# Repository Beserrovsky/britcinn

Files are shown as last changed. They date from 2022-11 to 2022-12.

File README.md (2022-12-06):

# Britney Cinnamon
Britney Cinnamon, an IOT device embedded in the light switch.

[versão em portguês aqui](README-pt.md)

## Idea

Check out [idea PDF](idea.pdf)

## Features

- Control over light switchs
- Door locking capability
- Voice commands
- Mqtt-based communication
- Data analysis via Database storage and API

## Stack

- Micropython for client firmware
- HiveMQ as public broker
- NodeJS + MongoDB app for storage and API access

## Relevant Links

 - Presentation video: https://youtu.be/LhZvgNEXjJY
 - Implementation and demonstration video: https://youtu.be/GOQ3h5-p_FI
 - Driver folder: https://drive.google.com/drive/u/0/folders/1Ou_RRr1SyYoGhryZdT9D95lgfnK7g_yX 
 - Secondary Repository (web page and app): https://github.com/Beserrovsky/britcinn-website

## Credits

[Hanashiro](https://github.com/Hanashiro2001)

[Felipe Beserra](https://github.com/Beserrovsky)

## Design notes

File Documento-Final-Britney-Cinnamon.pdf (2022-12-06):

### Escola Politécnica da Universidade de São Paulo

PSI 3542 - Sistemas Embarcados para IoT

Felipe Beserra (13683702)
Gabriel Kiyoki Hanashiro (13682020)

# Projeto Final: Britney Cinnamon

### São Paulo

2022

Felipe Beserra, Gabriel K. Hanashiro

# Projeto Final: Britney Cinnamon

Orientadores:
Prof. Sergio Takeo Kofuji
Fabrício Mansilla

São Paulo
2022

Resumo

Internet das Coisas (ou IoT) é a conexão dos objetos mundanos a internet, podendo ser aplicado em diversas áreas (médica, industrial, automação, etc). Aqui, descreve-se um projeto desenvolvido por alunos de graduação na Escola Politécnica da Universidade de São Paulo, apresentando um sistema completo de IoT cujas funcionalidades envolvem travas e lâmpadas inteligentes.

Sumário

Resumo | 2
1. Requisitos do projeto final | 4
1.1 Entregas | 4
1.2 Requisitos | 4
2. Projeto Final | 4
2.1 Lista de Componentes | 4
2.2 Descrição do sistema | 5
2.3 Implementação do sistema | 7
2.3.1 ESP client | 7
2.3.2 RASP client | 7
2.4 Utilização dos dispositivos | 8
2.4.1 Modelos | 8
2.4.2 Aplicativo e página web | 10
3. Marketing | 13
3.1 Comparação de mercado | 13
3.2 Marca | 14
4. Links importantes | 14
4.1 Links relacionados ao grupo | 14
4.2 Links de produtos para comparação de preços | 15

1. Requisitos do projeto final

O trabalho final da disciplina de IoT para Sistemas Embarcados é projetar e aplicar uma solução completa de IoT usando dispositivos embarcados de IoT.

1.1 Entregas
O trabalho final têm como entregas:
- Minimum Viable Product (MVP);
- Folder do sistema;
- Apresentação do projeto (marketing e técnica);
- Vídeo tutorial no youtube do projeto, com detalhes do passo-a-passo da implementação do sistema. Deve conter uma demonstração de uso;
- Arquivos dos códigos publicados no GitHub;
- Tutoriais no GitHub.

1.2 Requisitos
O produto final deverá englobar:
- Um (ou mais) dispositivo embarcado de IoT para sensoriamento/atuação, com capacidade de comunicação MQTT;
- Um Smart IoT device/gateway/edge com capacidade de interação humano-máquina por voz para gerenciamento dos dispositivos de IoT embarcados e integração com serviços em nuvem;
- Uma aplicação de monitoramento em nuvem, capaz de conversar com usuários através de redes sociais e página web;
- Um aplicativo para smartphone android.
2. Projeto Final

2.1 Lista de Componentes
Os componentes usados no projeto foram:
- Raspberry Pi;
- ESP32;
- DHT11;
- Servo motor;
- Módulo relé 3.3V - 127V;
- LED (para o protótipo);
- Resistor (para o protótipo);
- Mini interruptor de alternância (para o protótipo);
- Borne 2 vias;
- Mini fonte 5V.

2.2 Descrição do sistema
O projeto final do grupo usa um ESP32 como dispositivo IoT que se comunica com o smart hub unicamente via MQTT. O dispositivo IoT controlado seria instalado dentro do interruptor do cômodo e controlaria a luz com um relé, de maneira integrada com o próprio interruptor (ou seja, a mudança de estado é o que altera a luz), um DHT11 para captar a temperatura e umidade, e um servo motor atuando como o mecanismo de uma trava.
A alimentação do dispositivo será realizada com os próprios cabos de alimentação da lâmpada na parede, apenas passando por um conversor de tensão para se adaptar ao ESP32 (para o caso do protótipo, teremos um carregador de celular para fazer essa conversão).
Por ser um protótipo e devido às diversas mudanças de design pelo qual o projeto passa, o grupo usou uma placa ilhada de fibra de vidro 10x5 centímetros para fazer o sistema de alimentação do ESP (mantendo espaço para os outros componentes, para ter uma ideia de tamanho) e usou uma protoboard e um LED para realizar os testes e comprovar o funcionamento, imagens 1 e 2 respectivamente. Além disso, por não termos um microfone compatível com o Raspberry Pi, rodamos o código do smart hub no computador, porém ele é compatível com o mini-computador (apenas alterando o contexto do rhino para ser compatível com o sistema).

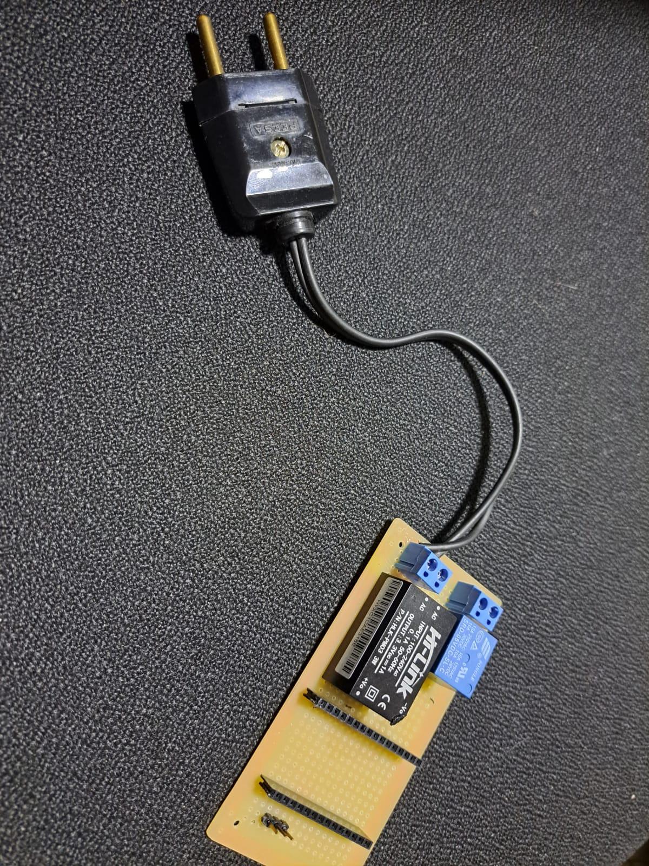
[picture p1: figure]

Imagem 1 - Protótipo do dispositivo IoT na protoboard. FONTE: Autoral.

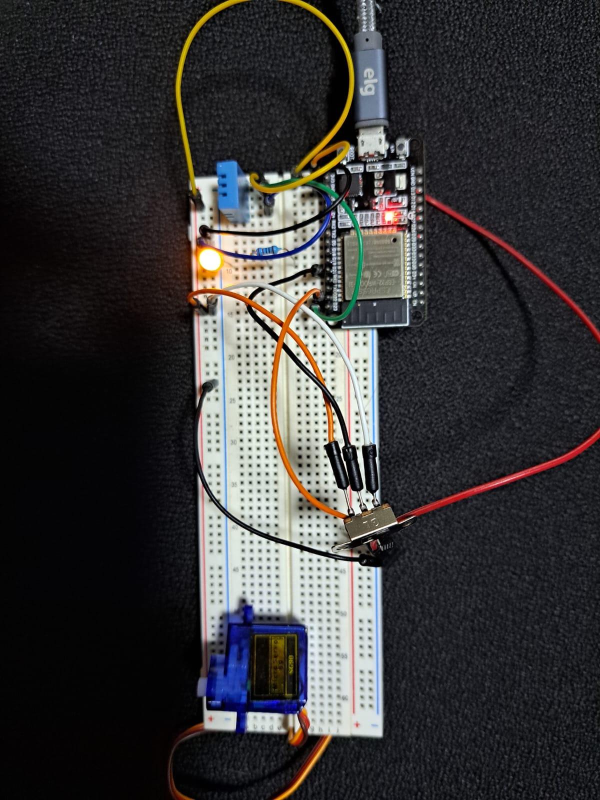
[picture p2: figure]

Imagem 1 - Protótipo do dispositivo IoT na protoboard. FONTE: Autoral.

A comunicação MQTT é realizada utilizando o broker EMQX, um serviço open source. A estrutura de comunicação, incluindo o broker, pode ser vista na imagem 2.

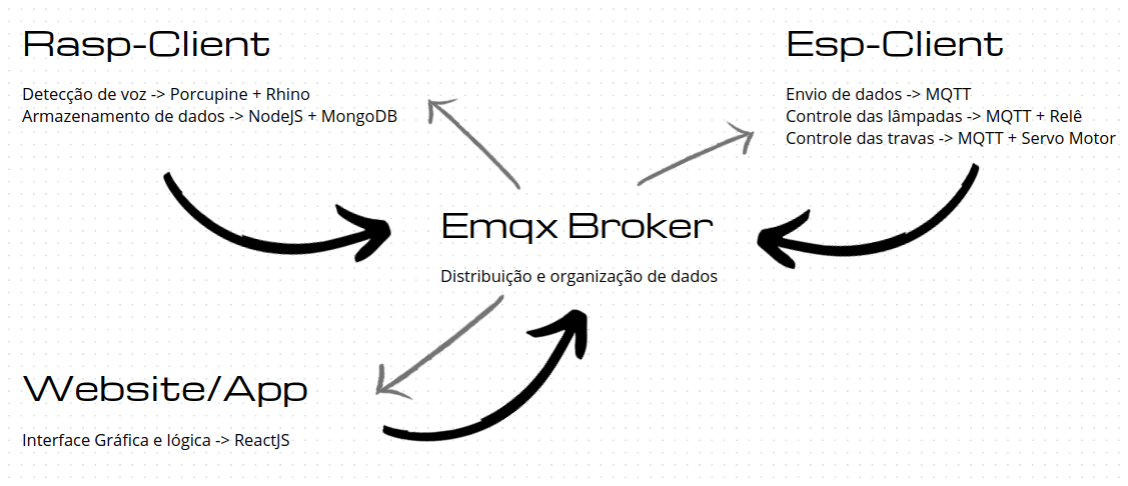
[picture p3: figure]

Imagem 2 - Estrutura de comunicação dos dispositivos. FONTE: Autoral.

O smart hub, no caso o raspberry pi, conecta na internet e se comunica com o ESP32 via MQTT, como mencionado anteriormente. Ele é a interface para comunicação humano-máquina, ou seja, interação por voz para controle do dispositivo IoT, funcionando com o PicoVoice (usando Porcupine e Rhino).
Temos apenas a palavra “Cinnamon” como wake word do dispositivo, pois “Britney” não está incluído no dicionário do PicoVoice. Apesar do porcupine funcionar com uma palavra em inglês, o speech-to-intent do Rhino funciona de acordo com a língua portuguesa; treinamos o contexto dele para obedecer aos comandos de ligar, desligar, trancar e destrancar.

2.3 Implementação do sistema

2.3.1 ESP client
O ESP32, como mencionado anteriormente, envia dados de temperatura e umidade do DHT11, o estado da lâmpada e da trava a cada 5 segundos, aproximadamente, além de um aviso toda vez que liga; e recebe comandos de mudança de estado da lâmpada e da trava. Ambos trocando informações com o Raspberry Pi via MQTT (todos os dados são enviados no formato JSON, sigla para JavaScript Object Notation).
Para isso, existem os códigos boot.py (para conexão com internet) e o código main.py, que utilizam as bibliotecas components.py (escrita pelo grupo especificamente para este projeto) e mqttsimple.py (de uso público). No main.py, há, inicialmente, uma rotina para tentar uma conexão com o broker MQTT, que caso falhe, o dispositivo reinicia e tenta de novo. Em seguida, são definidas funções para verificar se há novas informações em algum tópico MQTT e para mandar os dados do DHT11 que serão armazenados no Raspberry Pi para possíveis análises dos dados. Além delas, uma última função chama a rotina dos componentes para realizar a coleta de dados do DHT e o funcionamento dos outros componentes de acordo com as mudanças, ou falta delas.
No caso do interruptor inteligente, diferentemente de um comum, não há um estado ligado e um estado desligado, mas sim, um funcionamento semelhante a de um push button, pois a mudança de estado (apertando a switch, independente de direção) acende ou apaga a luz.

2.3.2 RASP client
O Raspberry Pi é o smart hub, isto é, o centro de inteligência que atua como assistente controlado por voz, host do servidor do app e dos outros serviços necessários para o funcionamento do dispositivo. Para tal, ele possui uma rotina para iniciar a comunicação MQTT, e uma conexão direta com o MongoDB (software de banco de dados).
Além disso, tem-se uma implementação do sistema porcupine, que serve para identificar a wake word (treinado com a palavra “Cinnamon”) e rhino, um software de speech-to-intent (com o contexto elaborado pelo grupo) para identificação de voz, ambos serviços gratuitos, porém limitados, do PicoVoice.
Por fim, o Raspberry Pi também possui a rotina necessária para rodar a página da web e o aplicativo.

2.4 Utilização dos dispositivos

2.4.1 Modelos
Para utilizar o sistema, primeiramente, elaboramos uma casa fictícia usando o aplicativo Revit da Autodesk para modelar o Floorplan da imagem 3, ele possui 2 quartos, 1 cozinha, 2 banheiros, 1 garagem, 1 sala e 1 área de serviço.

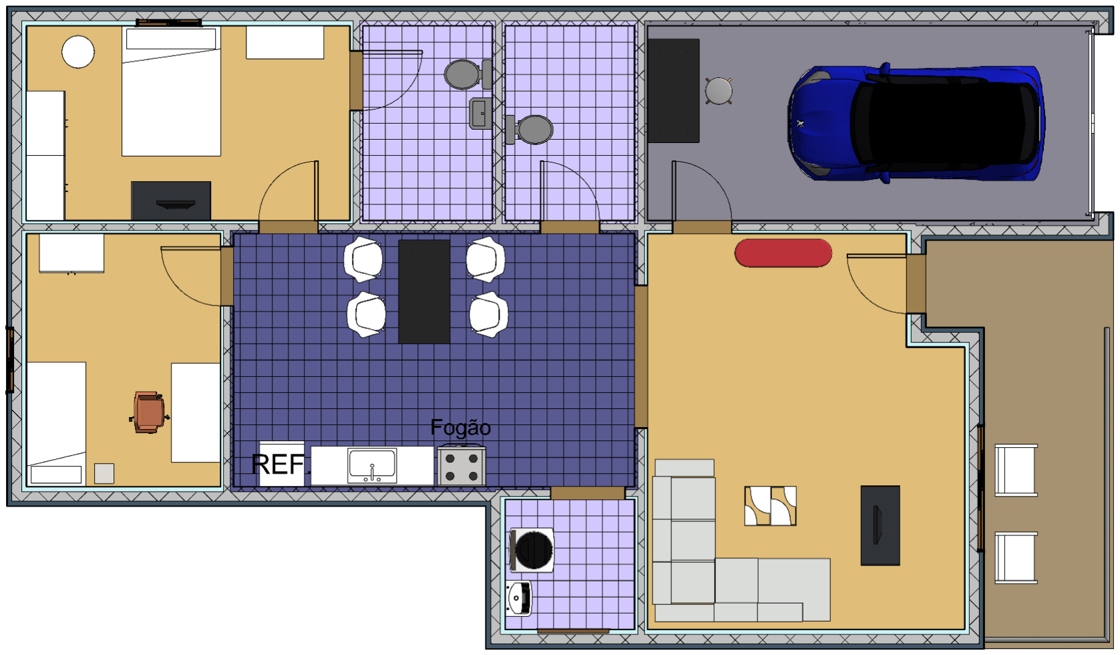
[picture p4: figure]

Imagem 3 - Floorplan feito no Revit. FONTE: Autoral

Para visualização, o grupo fez um modelo 3D usando o SolidWorks de acordo com o quarto de um dos integrantes do grupo, como pode ser visto na imagem 4 abaixo. Vemos que apenas o motor e o sistema da trava no geral devem ficar para fora da parede, que seria conectado via cabos com o dispositivo dentro do interruptor.

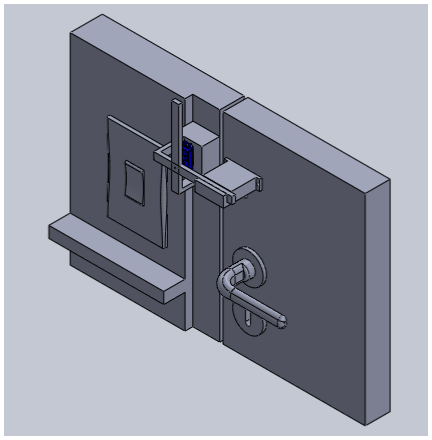
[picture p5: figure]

Imagem 4 - CAD da montagem da trava na parede FONTE: Autoral

Vale mencionar que na imagem acima, os dois estados da trava (trancado e destrancado) estão sendo exibidos ao mesmo tempo, quando na realidade, teria apenas uma barra servindo como tranca. O modelo, para evitar ter toda a força exercida sobre o servo motor, possui uma extensão da barra em um formato de gancho para se conectar com o próprio suporte do motor, como se pode ver na imagem 5 abaixo.

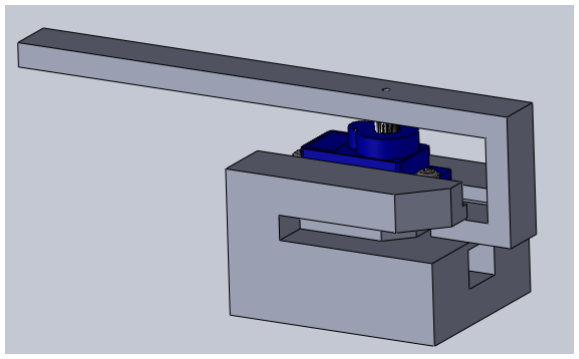
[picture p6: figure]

Imagem 5 - CAD da montagem do servo motor. FONTE: Autoral

2.4.2 Aplicativo e página web
A página da web foi feita usando a ferramenta “React”, de modo que ela consiga servir como um aplicativo de celular também, criando um atalho nele que leva ao site.
Tanto o aplicativo quanto a página da web seguem um mesmo princípio, o floorplan é exibido em uma tela com botões sobre cada cômodo controlando a luz (no caso da cozinha, sala, garagem e os quartos) e 2 botões controlando as travas (no caso dos dois quartos). No caso do protótipo, como há apenas um cômodo funcionando, há apenas 2 botões na tela (uma lâmpada e uma trava).

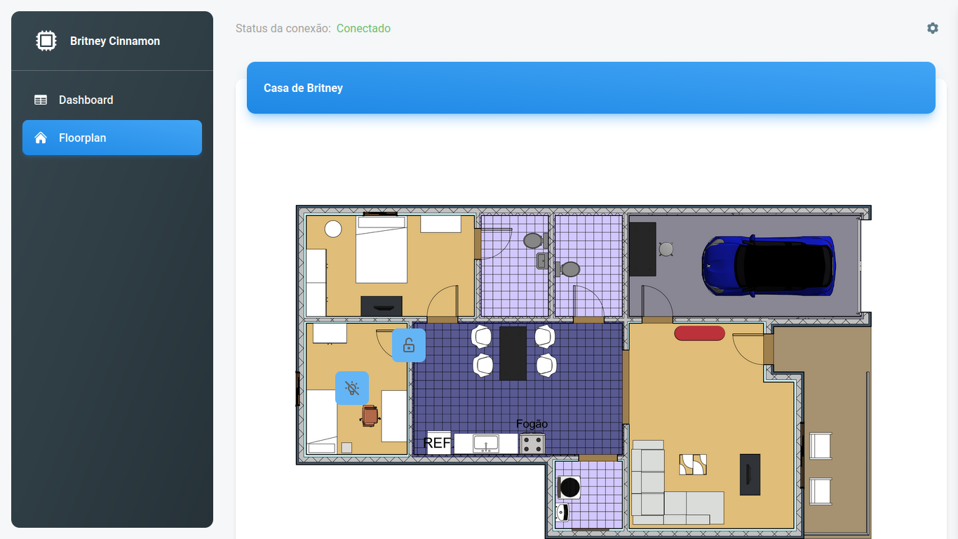
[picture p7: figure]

Imagem 6 - Aba da página web com o floorplan (lâmpada apagada). FONTE: Autoral

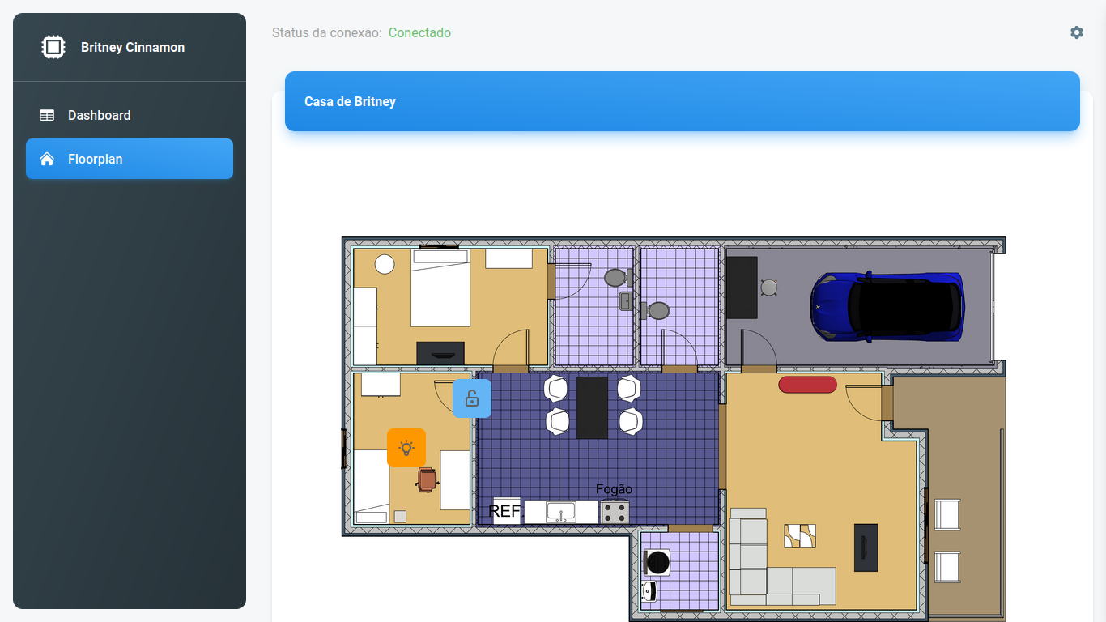
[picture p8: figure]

Imagem 6 - Aba da página web com o floorplan (lâmpada acesa). FONTE: Autoral

Em uma aba separada (tanto no celular quanto na página da web), temos o dashboard, no qual aparece a média dos últimos 10 dados coletados da temperatura e umidade recentes, e logo abaixo deles, todos os valores sendo exibidos em formato de gráficos. Além disso, temos uma área exibindo a quantidade de dispositivos (clients) online e um gerador de número aleatório que muda toda vez que o site recebe um pacote (atua como um indicador da atualização dos dados).

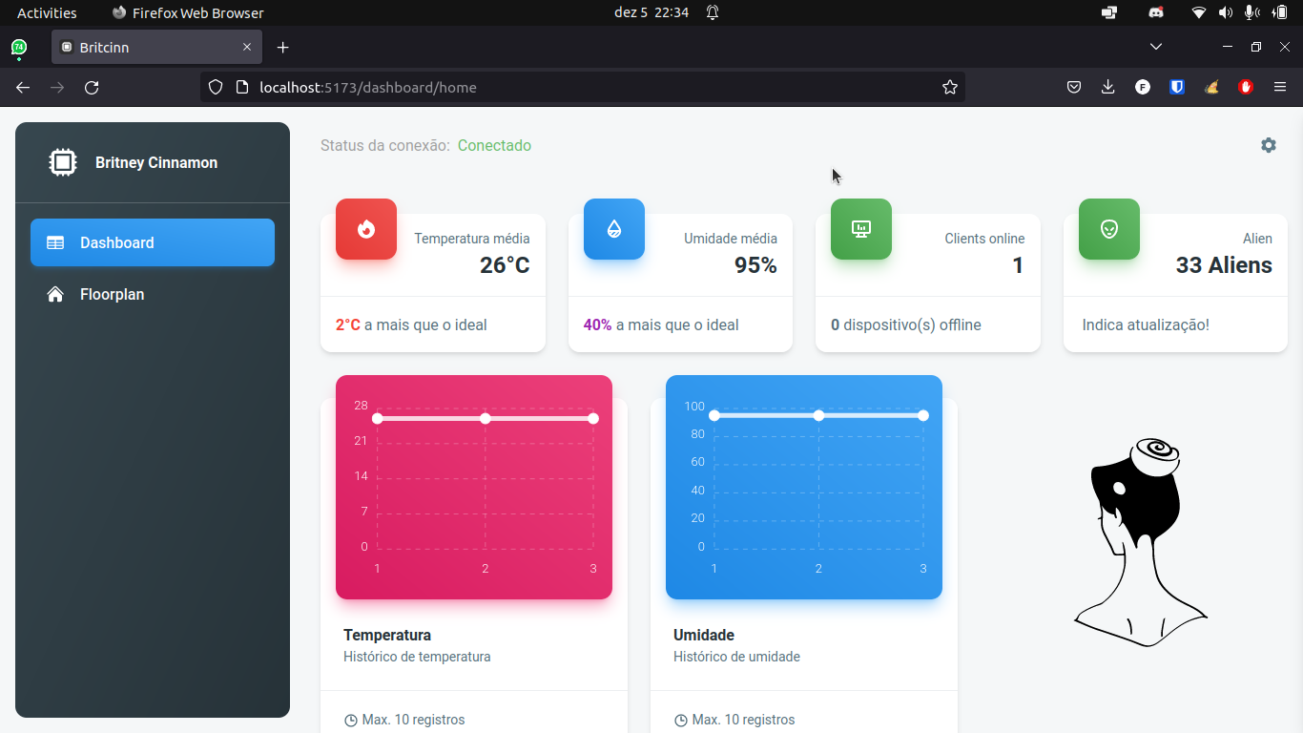
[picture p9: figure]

Imagem 7 - Aba da página web dashboard com o link FONTE: Autoral

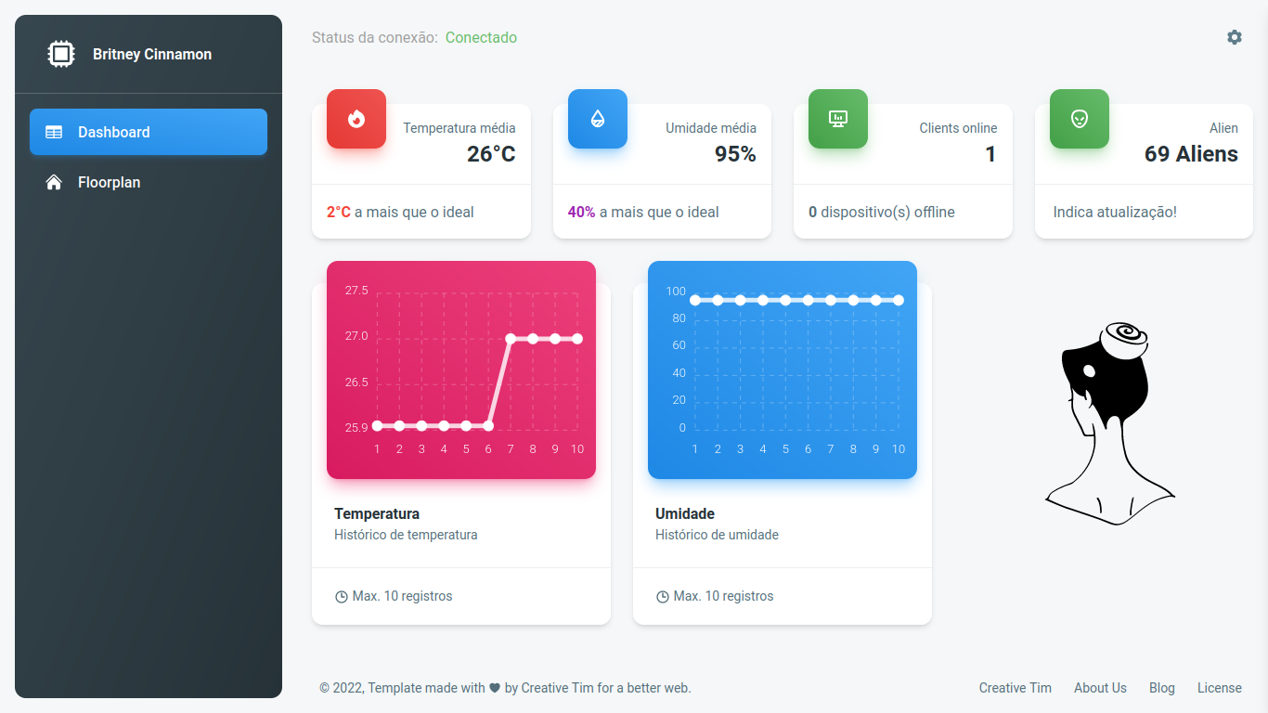
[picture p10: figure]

Imagem 7 - Aba da página web dashboard em tela cheia. FONTE: Autoral

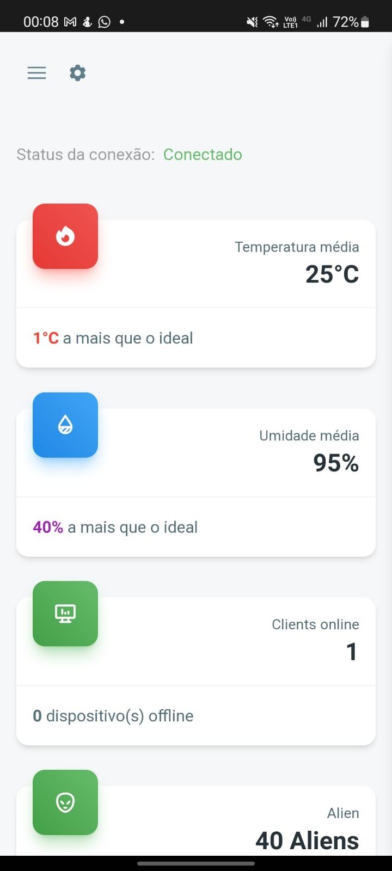
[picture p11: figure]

Imagem 7 - Aba da dashboard no aplicativo. FONTE: Autoral

3. Marketing

3.1 Comparação de mercado
O projeto final visa recriar os assistentes controlados por voz como a Alexa da Amazon e o Google Home Mini da Google e os dispositivos que eles são capazes de manipular. O resultado apresentado possui um grande valor acadêmico e um potencial econômico também. Feito por estudantes de graduação universitários, usando majoritariamente softwares e outros serviços open-source e gratuitos (todos são open-source, com exceção do PicoVoice), além de open-hardware também. Isto demonstra uma expansão na distribuição e oferta de tecnologia, como também a existência de aplicativos gratuitos que possuem recursos de qualidade aplicáveis em projetos pessoais capazes de simular, até certo ponto, os produtos de grandes empresas, como a Google e a Amazon.
Economicamente falando, atualmente o projeto é incapaz de competir com grandes empresas, no total, o projeto final teve um custo de R$792,00 (R$680,00 do raspberry pi 3; R$40,00 do ESP32; R$20,00 do servo motor; R$14,00 do DHT11; R$10,00 do relé; e R$8,00 da placa ilhada), sendo que o maior gasto foi o Raspberry pi, pois está passando por uma alta de preços devido a falta global de silício; enquanto um google home mini pode ser encontrado por aproximadamente R$200,00 e um echo dot da 4º Geração por R$400,00, estes com mais funções e sensores que o nosso projeto.
A vantagem, porém, deriva não do preço mas da capacidade de manipulação pelo usuário que o projeto desenvolvido possui. Enquanto os produtos comerciais visam uma privacidade do sistema que desenvolvem, o que acaba limitando o quanto se pode alterar as funcionalidade do dispositivo; o projeto do grupo apresenta uma capacidade de manipulação pelo usuário muito maior, um atrativo para muitos makers que desejam implementar um assistente controlado por voz em seus projetos pessoais. Outro ponto que se torna um atrativo no projeto é o dispositivo IoT. Este custou um total de R$92,00, enquanto outros em circulação, para somar uma aplicação semelhante a nossa, custaria em torno de R$340,00 (com uma lâmpada inteligente custando R$40,00; um interruptor inteligente R$100,00; e uma trava inteligente R$200,00). Disso, percebemos que há um aspecto economicamente competitivo desenvolvido, o dispositivo IoT, cujo preço é muito menor, também tendo um aspecto customizável pelo cliente, apesar de certas limitações de processamento.

Analisando em mais detalhes essa conclusão que obtivemos, temos que usando diversos dispositivos COTS (commercial-off-the-shelf), ou seja, dispositivos prontos, alcançamos um produto não otimizado, ou seja, um produto funcional, porém com desperdícios ao longo do caminho, uma vez que nenhum produto foi feito especificamente para atuar neste projeto em específico. Porém, mesmo com esses fatores, criou-se uma alternativa consideravelmente mais barata para dispositivos inteligentes capazes de comunicação e controle via internet, além de apresentar um fator de manipulação pelo usuário das funcionalidades dele.

Um aspecto interessante quanto ao nosso projeto é que o dispositivo IoT engloba 3 produtos comerciais em 1 (trava, lâmpada e interruptor inteligente), em um único controlador, algo não muito comum devido às limitações físicas e de processamento do dispositivo, mas que se bem aplicado pode trazer uma barateamento do produto sem queda de performance.

Em conclusão, percebemos que o produto tem grande valor acadêmico ao simular produtos comerciais de grandes empresas com recursos limitados e utilizando softwares e outros serviços gratuitos. Além disso, temos uma possibilidade de transformá-lo num produto economicamente viável, reapropriando elementos de funcionalidades mais amplas (como o ESP32 e o Raspberry pi) e manipulando diversos dispositivos com eles, mantendo ainda um aspecto mutável deles, ou seja, capacidade de alteração de código pelo usuário, e gerando um elemento funcional mais barato que os anteriores.

3.2 Marca
Para se tornar um produto comercial e competitivo, é necessário uma produção de componentes mais direcionados para a nossa aplicação, ao invés de usar microcontroladores gerais. Além disso, é necessário um foco em desenvolver produtos modulares e programáveis, com um diferencial em relação aos competidores, atraindo um nicho da população que gosta de manipular seus próprios dispositivos.

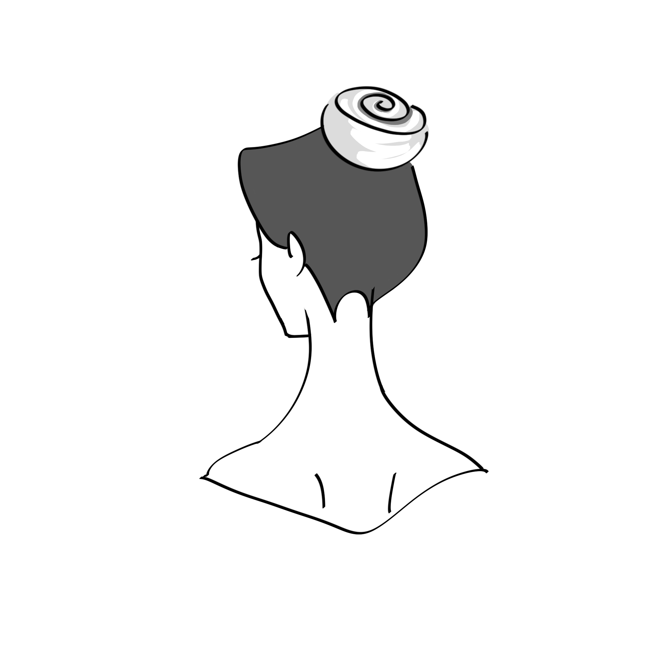
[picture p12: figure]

Imagem 8 - Logo Britney Cinnamon

4. Links importantes

4.1 Links relacionados ao grupo
Repositório do GitHub principal: https://github.com/Beserrovsky/britcinn

Repositório do GitHub para o aplicativo: https://github.com/Beserrovsky/britcinn-website

Pasta no drive:
https://drive.google.com/drive/u/0/folders/1Ou_RRr1SyYoGhryZdT9D95lgfnK7g_y X (https://drive.google.com/drive/u/0/folders/1Ou_RRr1SyYoGhryZdT9D95lgfnK7g_yX)

Vídeo Apresentação: https://youtu.be/LhZvgNEXjJY

Vídeo Passo-a-passo da implementação do projeto: https://youtu.be/GOQ3h5-p_FI

E-mail dos participantes: felipebeserra25@usp.br; gabriel.hanashiro@usp.br.

4.2 Links de produtos para comparação de preços

https://produto.mercadolivre.com.br/MLB-2755111466-tranca-inteligente-xiaomi-bluetooth-para-portas-e-gavetas-_JM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 &matt_product_id=MLB2755111466&matt_product_partition_id=1402952723409& matt_target_id=pla-1402952723409&gclid=Cj0KCQiAvqGcBhCJARIsAFQ5ke6_BD JOCX-Ub-txZAVmqphdA1dDIWKToDMyZPtRRhRYta6VvT3E6q4aAhZREALw_w cB (https://produto.mercadolivre.com.br/MLB-2755111466-tranca-inteligente-xiaomi-bluetooth-para-portas-e-gavetas-_JM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)

https://curtocircuito.com.br/placa-doit-esp32-esp32-wroom-32d-wifi-bluetooth.html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 vq3RRFcoNwQ0yJAeuU3I5zsGMQ1EAaAip6EALw_wcB (https://curtocircuito.com.br/placa-doit-esp32-esp32-wroom-32d-wifi-bluetooth.html?hsa_acc=7016354091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)

https://www.amazon.com.br/Placa-Raspberry-Quadcore-1-2ghz-Bluetooth/dp/B01CD5VC92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 (https://www.amazon.com.br/Placa-Raspberry-Quadcore-1-2ghz-Bluetooth/dp/B01CD5VC92?hvadid=379816377800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)

https://www.baudaeletronica.com.br/placa-padr-o-tipo-ilha-10x5-cm.html

https://www.baudaeletronica.com.br/sensor-de-umidade-e-temperatura-dht11.htmlhttps://www.americanas.com.br/produto/2388979154?offerId=5f8f7b421b186381b5dc0991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 (https://www.americanas.com.br/produto/2388979154?offerId=5f8f7b421b186381b5dc0991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)

&gclsrc=aw.ds&gclid=Cj0KCQiAvqGcBhCJARIsAFQ5ke6-nFliadjj88Fy7oeqK-KR 8UgHOPR0816nYJraDkxFozEgepijrpYaAuGjEALw_wcB (https://www.americanas.com.br/produto/2388979154?offerId=5f8f7b421b186381b5dc0991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)

https://www.amazon.com.br/Novo-Echo-Dot-4%C2%AA-gera%C3%A7%C3%A3o/dp/B084DWCZY6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 (https://www.amazon.com.br/Novo-Echo-Dot-4%C2%AA-gera%C3%A7%C3%A3o/dp/B084DWCZY6?hvadid=404840237192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)

https://www.baudaeletronica.com.br/modulo-rele-5v.html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 (https://www.baudaeletronica.com.br/modulo-rele-5v.html)

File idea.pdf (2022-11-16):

Escola Politécnica da Universidade de São Paulo Sistemas Embarcados para IoT - PSI 3542

Felipe Beserra - 13683702
Gabriel Kiyoki Hanashiro - 13682020

# Descrição do Sistema

## Trabalho final de PSI 3542

Orientador: Sergio Takeo Kofuji

São Paulo
2022

Introdução
Este documento tem como objetivo apresentar alguns detalhes iniciais do projeto elaborado por Felipe Beserra e Gabriel Hanashiro, para o trabalho final da disciplina de PSI3542 - Sistemas Embarcados para IoT.
Aqui, estão informações quanto ao Floorplan utilizado para o projeto, os dashboards que serão desenvolvidos (para página web e para aplicativo de celular) e informações quanto às capacidades do assistente de voz.

SUMÁRIO

Introdução | 1
O Trabalho Final | 3
Requisitos Mínimos | 3
O Projeto do Grupo | 3
Floorplan | 4
Dashboard | 4
Dashboard #1 | 4
Dashboard #2 | 5
Assistente de voz | 6
Intenção | 6
Entidades | 6
Diálogo | 6

O Trabalho Final
O trabalho final da disciplina é um resultado de tudo que foi passado ao longo do semestre, sendo necessário realizar uma solução completa de IoT utilizando dispositivos embarcados IoT.

Requisitos Mínimos
Quanto aos pré-requisitos do sistema, eles são:
- 1 ou mais dispositivo(s) embarcado(s) de IoT para sensoriamento/atuação, com capacidade de comunicação MQTT;
- 1 Smart IoT Device/Gateway/Edge com capacidade de interação humano-máquina por voz e gerenciamento dos dispositivos de IoT embarcados e integração com serviços em nuvem;
- 1 aplicação de monitoramento em nuvem, capaz de conversar com usuários através de redes sociais e página web;

Visualmente, é necessário que o projeto siga a seguinte estrutura:

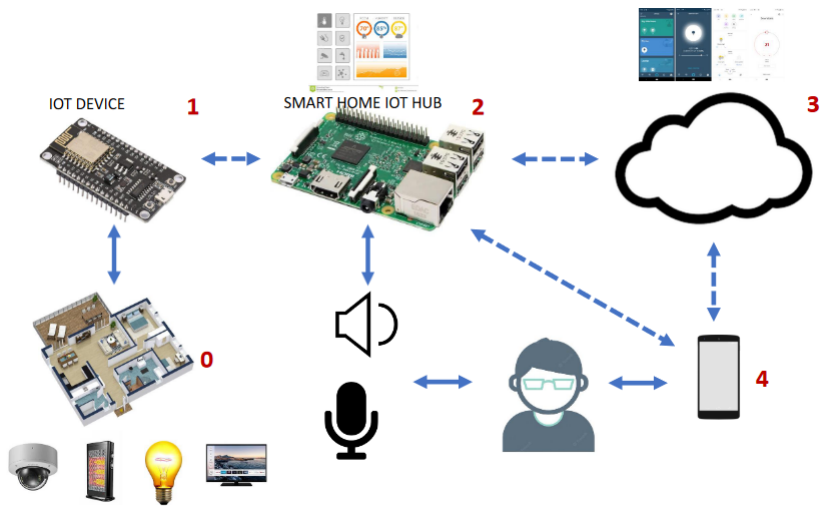
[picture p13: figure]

Imagem 1 - Estrutura do trabalho final. Propriedade do professor do curso.

O Projeto do Grupo

O projeto concebido pelo grupo, vai garantir todos os requisitos mínimos mencionados no tópico acima, evidentemente, e terá como objetos IoT: luzes e travas inteligentes utilizando ESP se comunicando via internet (MQTT) com uma página web, um aplicativo de celular e uma assistente de voz.

Abaixo, estão mais detalhes quanto a tópicos específicos do projeto (floorplan, dashboard e assistente de voz).

Floorplan
O floorplan do grupo será baseado na planta pronta abaixo (imagem 1), com 2 quartos, 2 banheiros, 1 cozinha, 1 área de serviço, 1 sala, 1 garagem, mantendo todos os cômodos existentes nela, porém com medidas diferentes das apresentadas na imagem. Além disso, a planta terá seu formato levemente modificado para poder ser incluída uma varanda na entrada da casa.
O floorplan será integrado aos dashboards de maneira dinâmica, para poder servir de mapa como guia dos dispositivos espalhados pela casa, servindo também como indicadores do estado de cada componente.

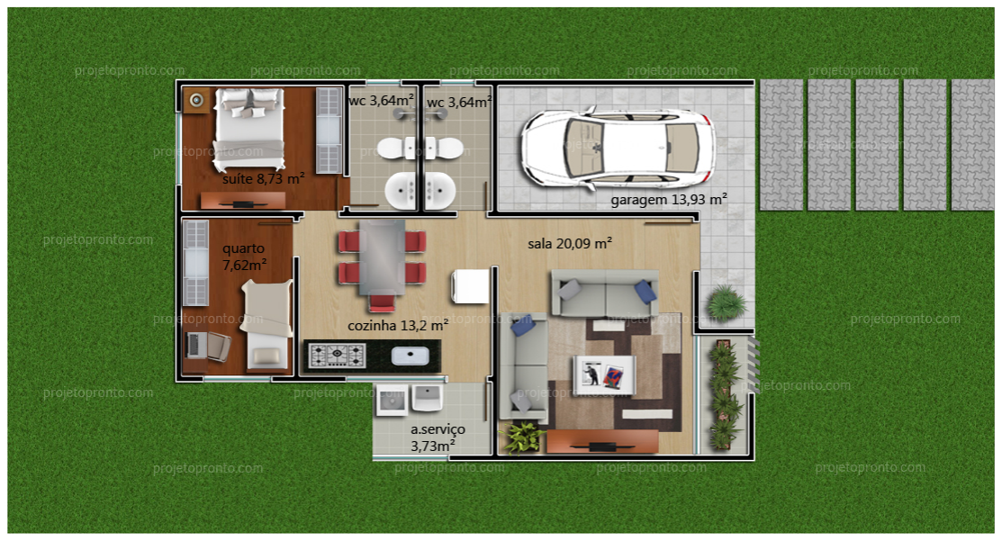
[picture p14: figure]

Imagem2 - Planta base do projeto do grupo Imagem disponível em: https://projetopronto.com/imagens/T11/big_h_t.jpg

Dashboard

Dashboard #1
Este será o dashboard disponível via página web, ela será feita com node-red e terá um mapa da casa, com símbolos que indicam o estado dos dispositivos IoT (por exemplo uma lâmpada, ele indicaria se está acesa ou desligada). Além disso, teremos os controles para a trava e para as luzes da casa, e uma área designada para as informações meteorológicas do local.
O plano é que o dashboard #1 se assemelhe a imagem seguinte:

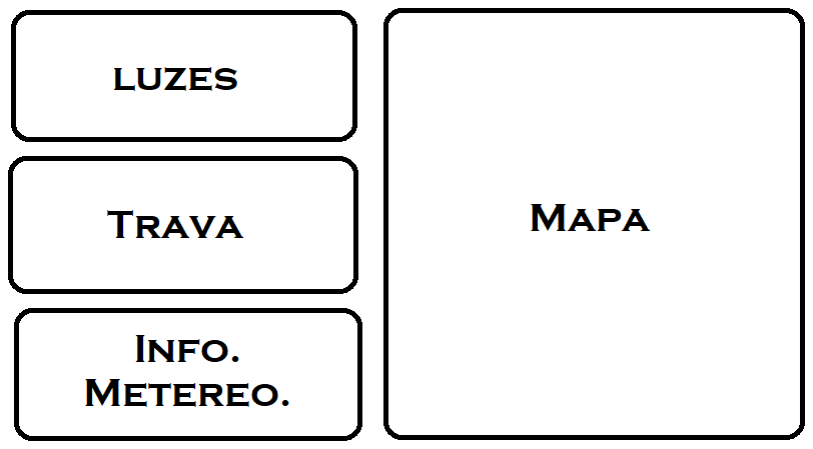
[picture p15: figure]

Imagem 3 - Rascunho do Dashboard #1 Propriedade intelectual do grupo

Dashboard #2
O dashboard #2 será o aplicativo de celular, e este deverá ter todas as mesmas funções que o primeiro dashboard (para computador), apenas com uma diferença no layout. O plano é que o dashboard #2 se assemelhe a imagem seguinte:

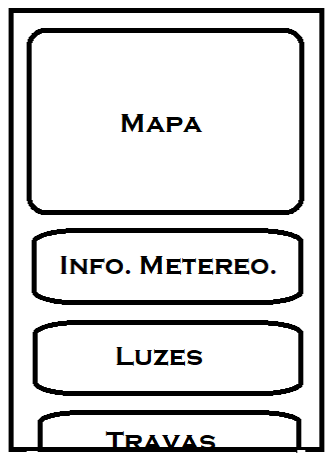
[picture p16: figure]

Imagem 4 - Rascunho do dashboard #2 Propriedade intelectual do grupo

Assistente de voz

Intenção
O assistente de voz deverá ser capaz de ligar ou desligar as luzes dos ambientes, ativar as travas localizadas nas portas e informar os estados deles, além das informações meteorológicas do local. Como intenção, teremos palavras como “ligar”, “desligar”, “trancar”, “destrancar”, “estado”, ”luz”, “trava”, “temperatura” e “umidade”.
No caso das travas, é provável que sua utilização seja feita apenas com alguma senha ou outra segurança semelhante, para que apenas o dono da trava consiga controlá-la.

Entidades
Como sistemas IoT, teremos lâmpadas e travas inteligentes, nomeadas ou numeradas de acordo com o cômodo controladas via ESP; e um sensor de temperatura e umidade, além, é claro, do dispositivo para realizar a comunicação humano-máquina (assistente de voz).
Para manter a comodidade e simplicidade de um interruptor tradicional, pretendemos manter também a funcionalidade física do controle via botão, mas este estará integrado no ecossistema IOT para funcionar como um atuador inteligente e não apenas físico (interrompendo a passagem de corrente no fio da lâmpada).

Diálogo
O wake word seria o nome do dispositivo. Ele seria capaz de responder verbalmente informações quanto ao estado dos dispositivos IoT e as informações meteorológicas do local.

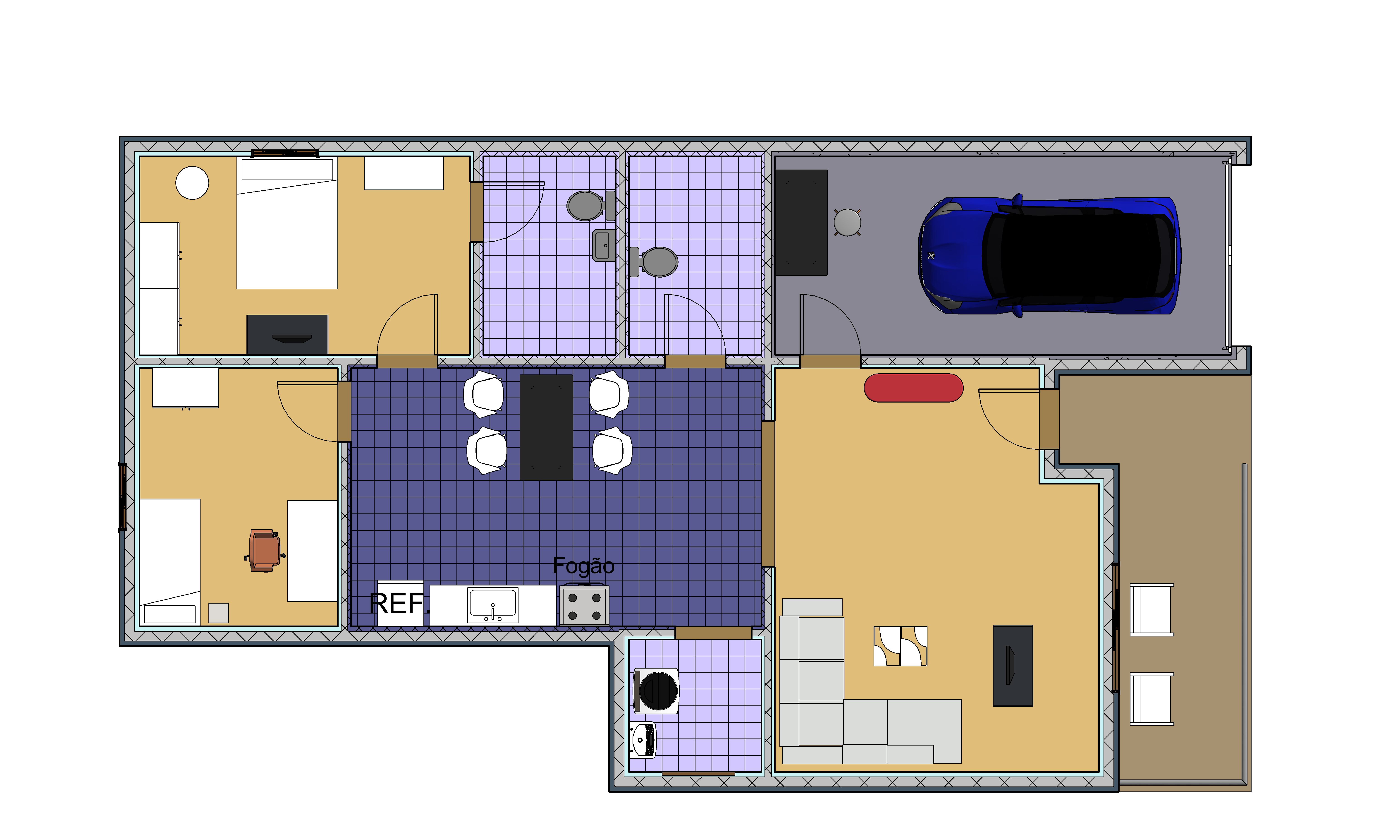
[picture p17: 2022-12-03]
floorplan/FLOORPLAN_PSI.tif

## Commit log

2022-11-29 Some Schematics stuff
    [britcinn_eletronics.kicad_pcb, britcinn_eletronics.kicad_sch]
2022-12-03 Renamed stuff
    [britcinn_eletronics.kicad_pcb, britcinn_eletronics.kicad_sch]
2022-12-04 Relay fixed
